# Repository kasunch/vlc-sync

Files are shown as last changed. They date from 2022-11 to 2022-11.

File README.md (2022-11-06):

# Harmony: A Time Synchronisation System for VLC Access Points

## About
This repository contains the implementation files for the paper titled **Harmony: A Time Synchronisation System for Visible Light Communication Access Points** published in ACM SenSys 2022. Access the paper here.

## Electronic Hardware

The electronic hardware consists of three modules.
* OWC Receiver module
* OWC Transmitter module
* ADC & DAC module

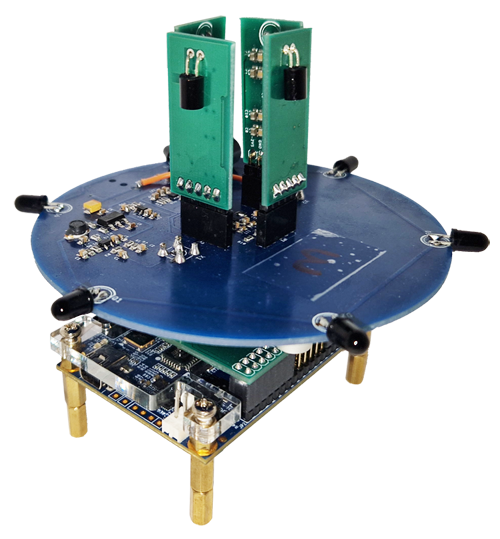
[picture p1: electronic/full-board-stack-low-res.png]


## Digital Hardware

The digital hardware implementation is done in Verilog.

**Note:**

The electronic and digital hardware implementations are fast-developed prototypes. Therefore, the implementations have several places which can be optimised.

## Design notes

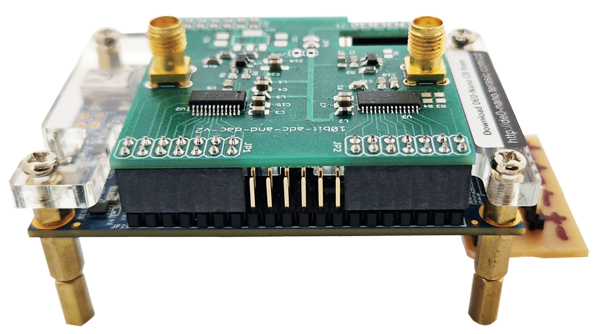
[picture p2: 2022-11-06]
electronic/10bit-adc-and-dac-low-res.png

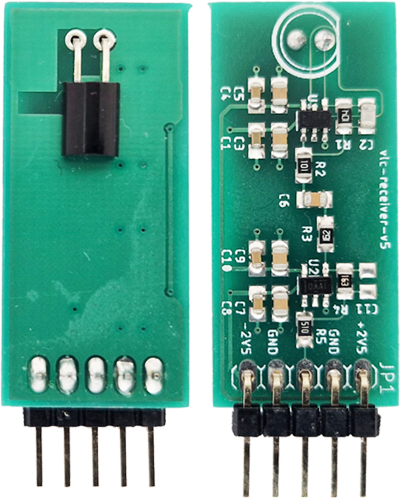
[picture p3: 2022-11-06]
electronic/owc-receiver-low-res.png

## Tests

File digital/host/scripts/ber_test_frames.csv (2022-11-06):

7c | 00 | 00 | 01 | 02 | 1e | 10 | 02 | 04 | 3c | 20 | 04 | 08 | 78 | 40 | 09 | 10 | 70 | 00 | 12 | 20 | 60 | 01 | 24 | 40 | 40 | 03 | 48 | 00 | 00 | 07 | 10 | 00 | 01 | 0f | 21 | 01 | 02 | 1e | 43 | 02 | 04 | 3c | 07 | 04 | 08 | 78 | 0e | 09 | 10 | 70 | 1d | 12 | 20 | 60 | 3b | 24 | 40 | 40 | 77
7c | 01 | 00 | 04 | 09 | 77 | 48 | 08 | 12 | 6e | 10 | 10 | 24 | 5c | 21 | 20 | 48 | 38 | 43 | 41 | 10 | 70 | 07 | 02 | 20 | 61 | 0e | 05 | 41 | 42 | 1d | 0b | 02 | 04 | 3b | 17 | 04 | 09 | 77 | 2f | 08 | 12 | 6e | 5e | 10 | 24 | 5c | 3c | 20 | 48 | 38 | 79 | 41 | 10 | 70 | 73 | 02 | 20 | 61 | 67
7c | 02 | 00 | 12 | 20 | 67 | 05 | 24 | 41 | 4f | 0b | 49 | 02 | 1e | 17 | 12 | 04 | 3d | 2f | 25 | 09 | 7a | 5e | 4a | 12 | 74 | 3c | 15 | 24 | 68 | 79 | 2a | 49 | 50 | 73 | 55 | 12 | 20 | 67 | 2b | 24 | 41 | 4f | 56 | 49 | 02 | 1e | 2d | 12 | 04 | 3d | 5b | 25 | 09 | 7a | 36 | 4a | 12 | 74 | 6d
7c | 03 | 00 | 00 | 52 | 6d | 15 | 00 | 24 | 5a | 2a | 01 | 48 | 35 | 55 | 03 | 10 | 6a | 2b | 07 | 20 | 55 | 56 | 0f | 40 | 2a | 2d | 1f | 00 | 54 | 5b | 3e | 00 | 29 | 36 | 7c | 00 | 52 | 6d | 78 | 00 | 24 | 5a | 70 | 01 | 48 | 35 | 60 | 03 | 10 | 6a | 40 | 07 | 20 | 55 | 01 | 0f | 40 | 2a | 03
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

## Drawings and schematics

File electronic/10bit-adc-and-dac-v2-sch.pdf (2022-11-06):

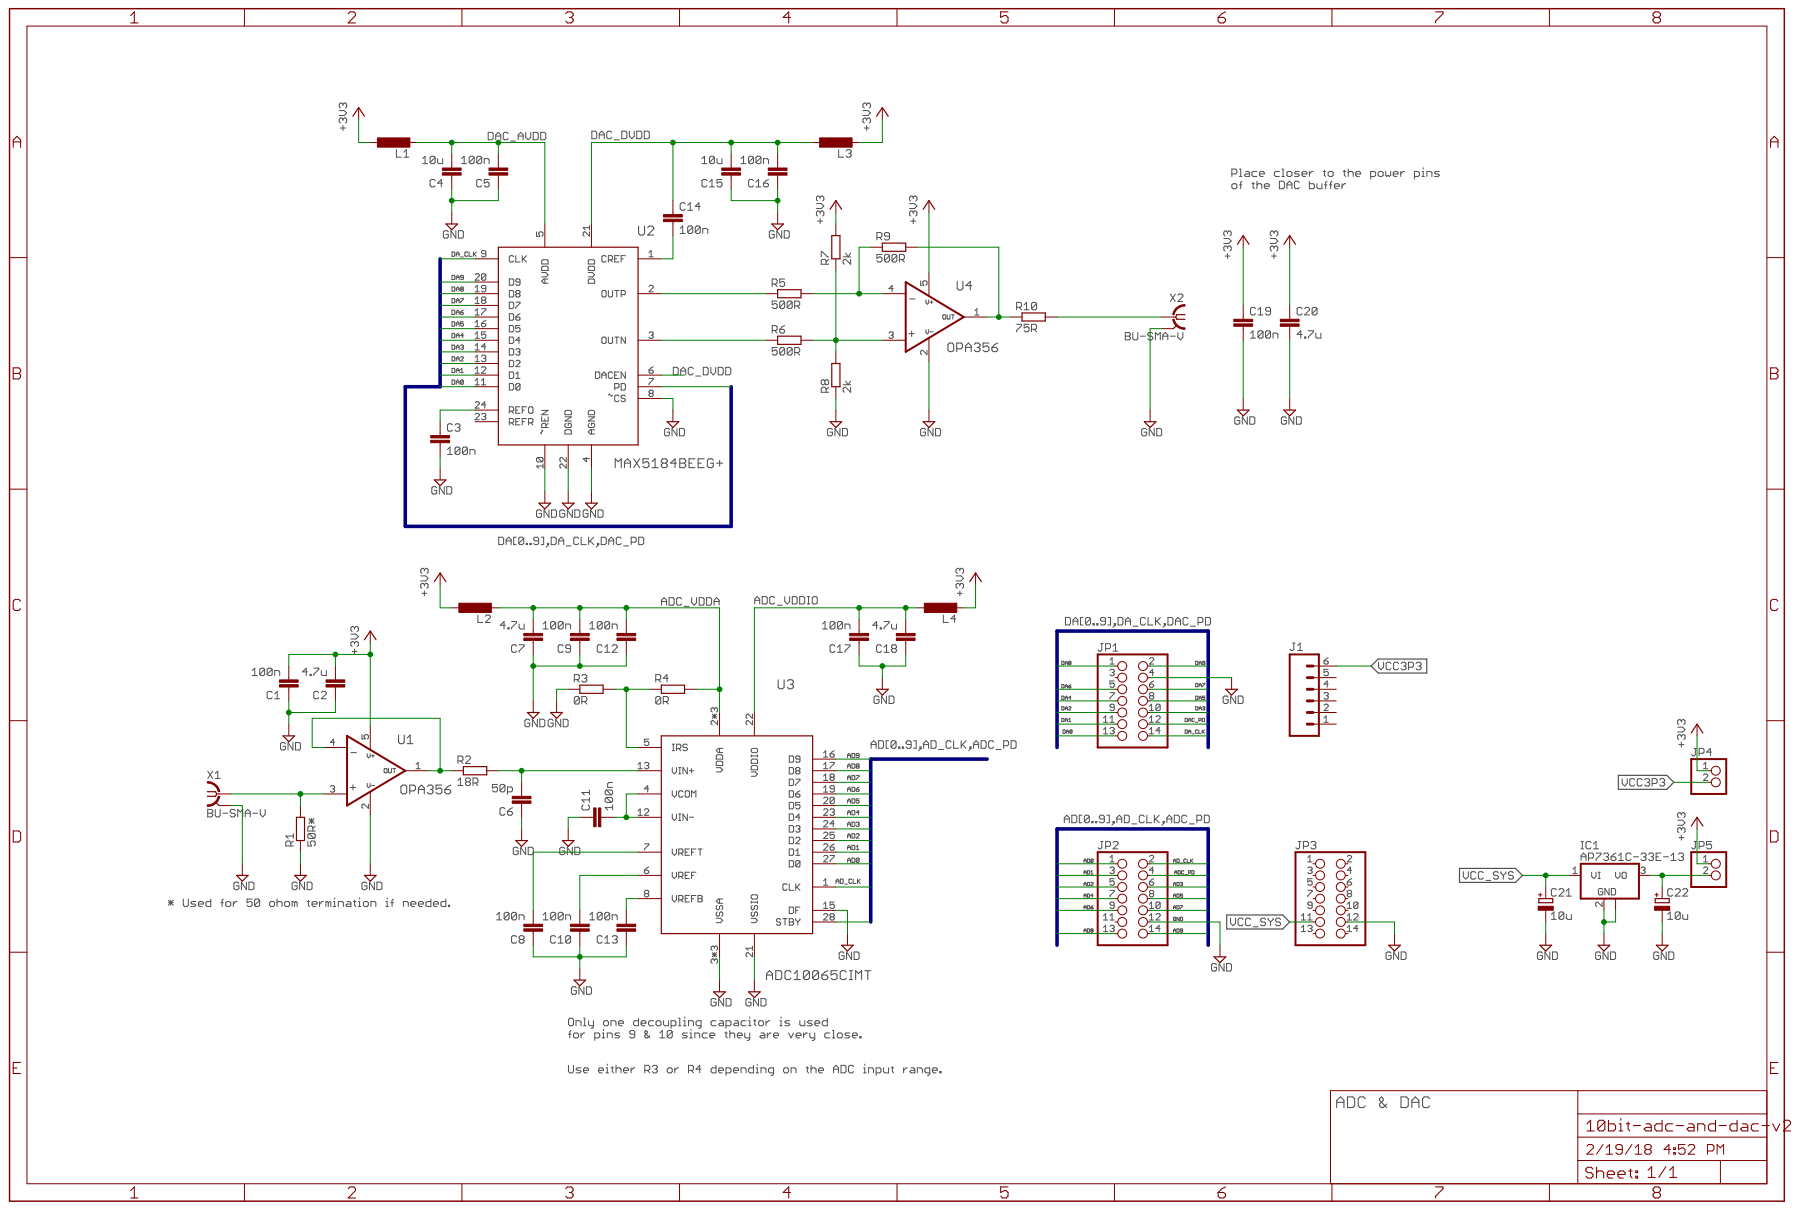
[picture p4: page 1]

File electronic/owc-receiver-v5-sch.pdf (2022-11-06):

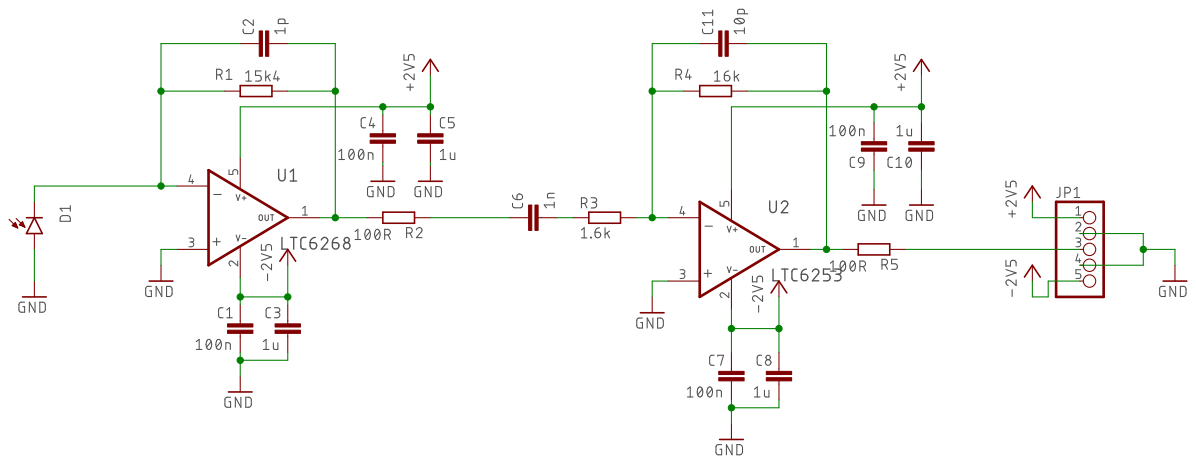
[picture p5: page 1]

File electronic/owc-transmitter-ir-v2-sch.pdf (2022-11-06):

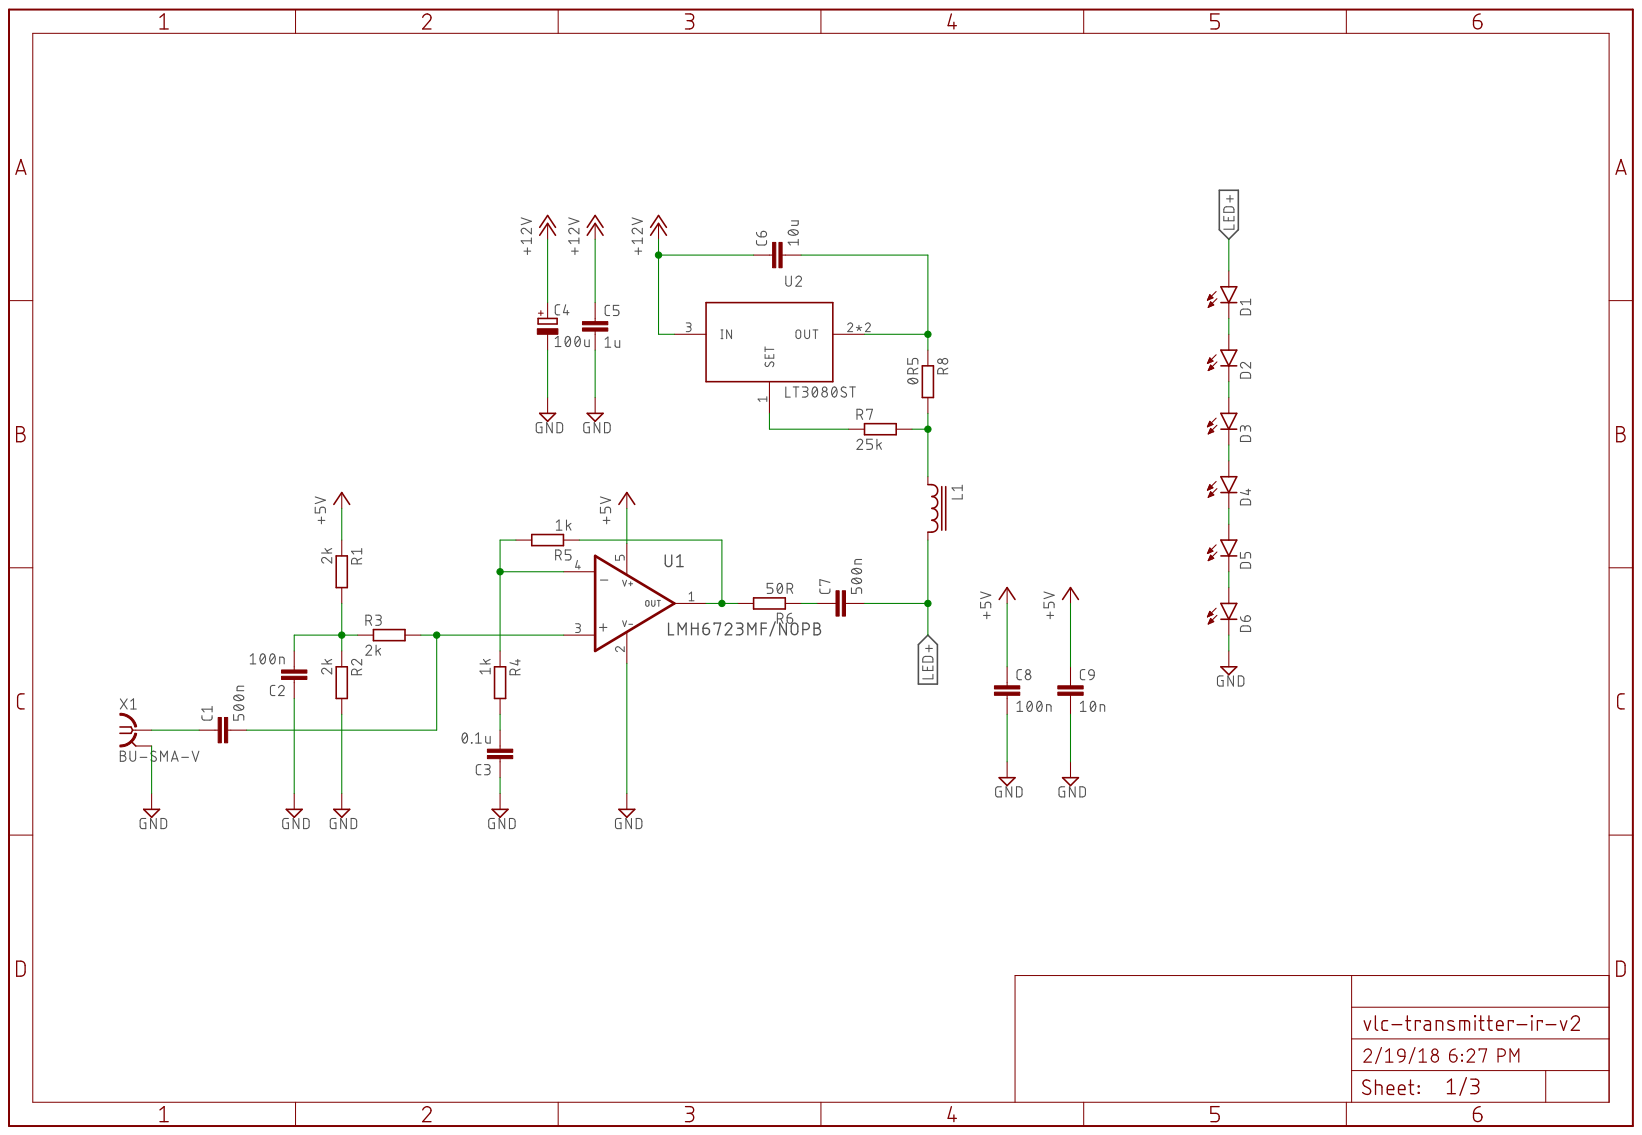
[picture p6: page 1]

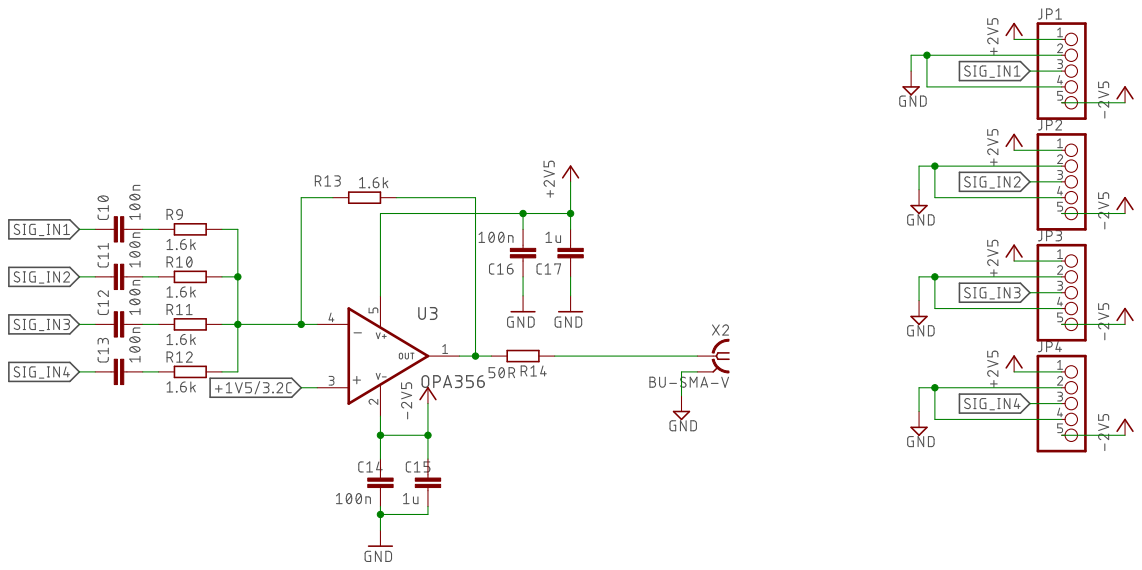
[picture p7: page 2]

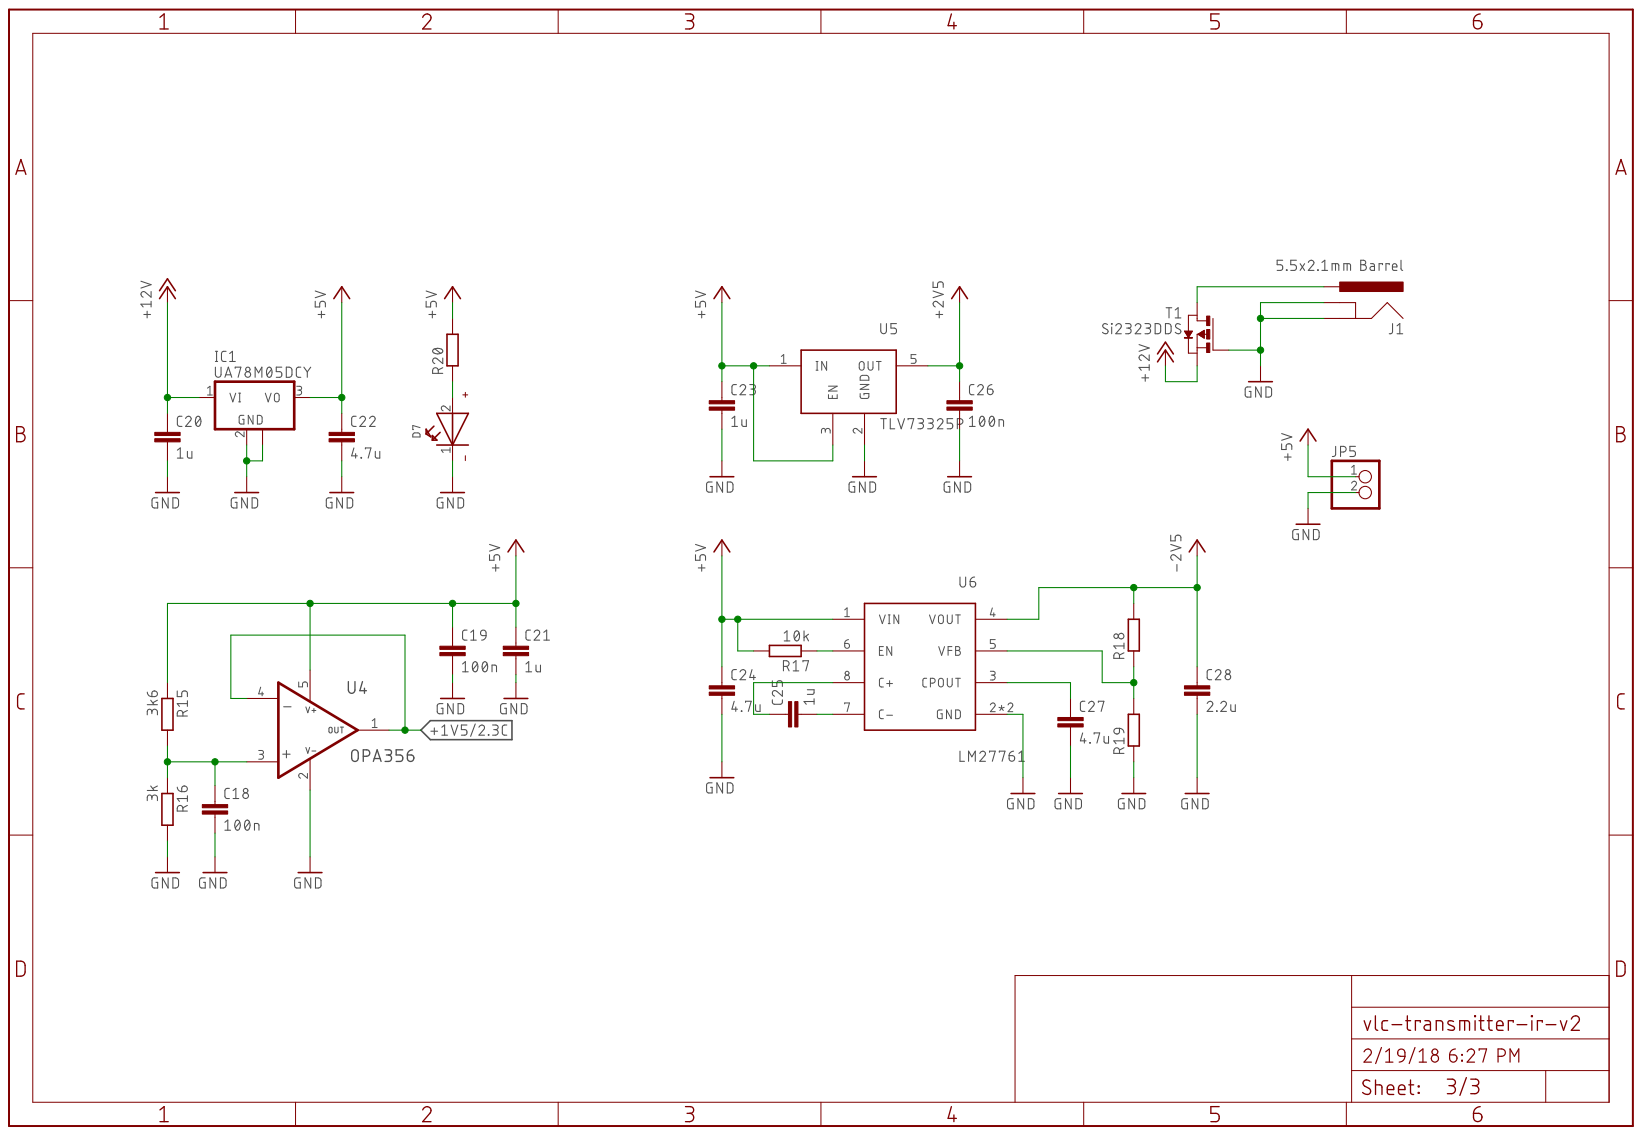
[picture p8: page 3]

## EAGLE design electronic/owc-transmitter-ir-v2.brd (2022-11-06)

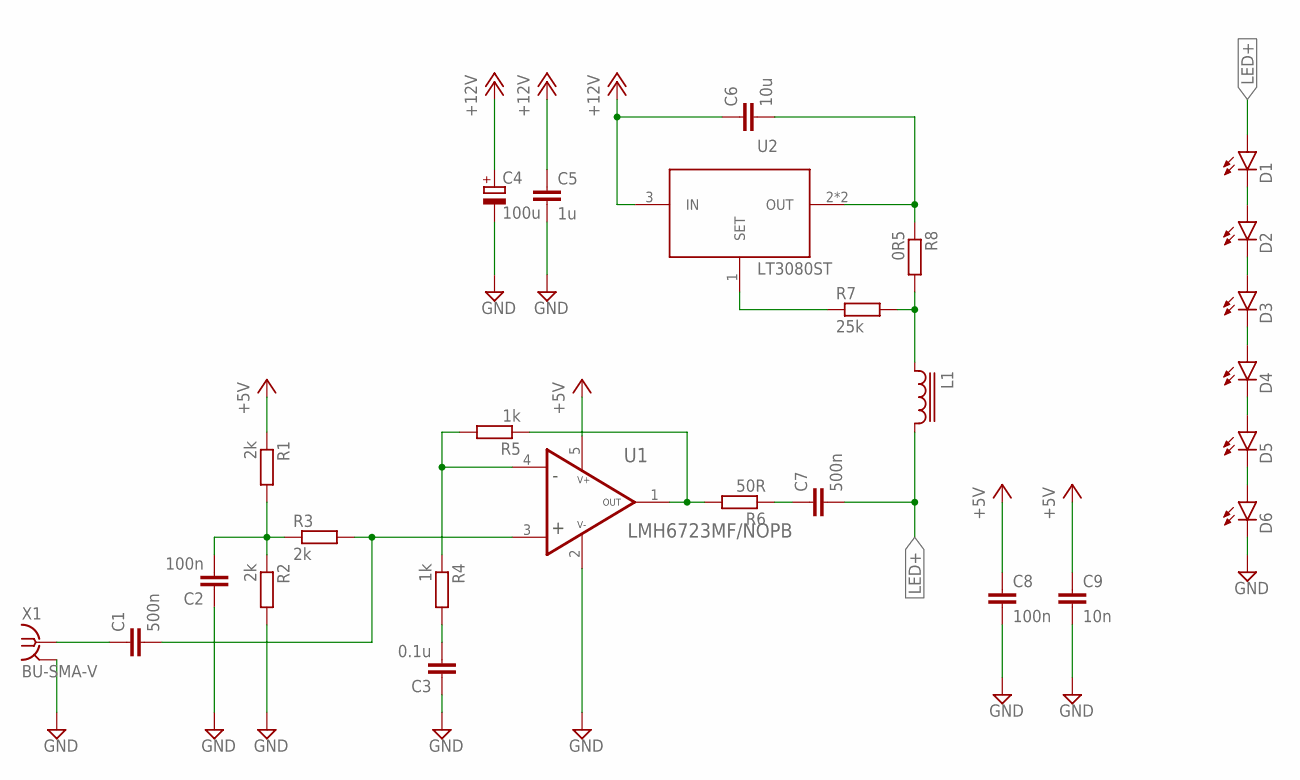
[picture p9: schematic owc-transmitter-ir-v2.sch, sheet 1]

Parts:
C1, C7: 500n; C0805
C2, C8: 100n; C0805
C3: 0.1u; C0805
C4: 100u; CT3528
C5: 1u; C0805
C6: 10u; C0805
C9: 10n; C0805
D1, D2, D3, D4, D5, D6: LED5MM
L1: SRR6603
R1, R2, R3: 2k; R0805
R4, R5: 1k; R0805
R6: 50R; R0805
R7: 25k; R0805
R8: 0R5; R0805
U1: LMH6723MF/NOPB; SOT23-5L
U2: LT3080ST; SOT223
X1: BU-SMA-V

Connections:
+5V: C8.1, C9.1, R1.1, U1.5 (V+); also elsewhere on the board
+12V: C4.+, C5.1, C6.1, U2.3 (IN); also elsewhere on the board
GND: C2.1, C3.1, C4.-, C5.2, C8.2, C9.2, D6.K (C), R2.2, U1.2 (V-), X1.2, X1.3 (2), X1.4 (2), X1.5 (2); also elsewhere on the board
LED+: C7.2, D1.A, L1.P$2 (2)
unnamed: D1.K (C), D2.A
unnamed: D2.K (C), D3.A
unnamed: D3.K (C), D4.A
unnamed: D4.K (C), D5.A
unnamed: D5.K (C), D6.A
unnamed: R5.1, R6.2, U1.1 (OUT)
unnamed: C7.1, R6.1
unnamed: R4.1, R5.2, U1.4 (IN-)
unnamed: C6.2, R8.1, U2.2 (OUT), U2.4 (OUT)
unnamed: C3.2, R4.2
unnamed: L1.P$1 (1), R7.2, R8.2
unnamed: C2.2, R1.2, R2.1, R3.1
unnamed: C1.1, X1.1
unnamed: R7.1, U2.1 (SET)
unnamed: C1.2, R3.2, U1.3 (IN+)

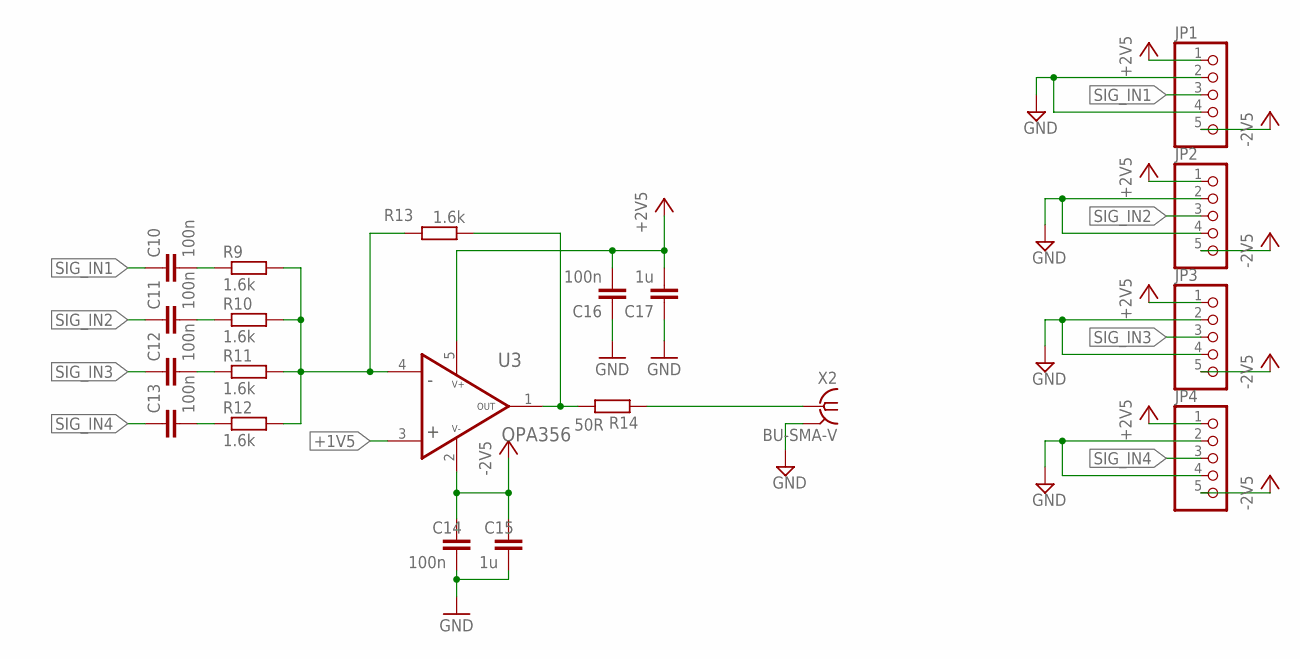
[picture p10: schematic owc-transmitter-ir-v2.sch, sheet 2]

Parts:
C10, C11, C12, C13, C14, C16: 100n; C0805
C15, C17: 1u; C0805
JP1, JP2, JP3, JP4: PINHD-1X5; 1X05
R9, R10, R11, R12, R13: 1.6k; R0805
R14: 50R; R0805
U3: OPA356; SOT23-5L
X2: BU-SMA-V

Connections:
+1V5: U3.3 (IN+); also elsewhere on the board
+2V5: C16.2, C17.2, JP1.1, JP2.1, JP3.1, JP4.1, U3.5 (V+); also elsewhere on the board
-2V5: C14.1, C15.1, JP1.5, JP2.5, JP3.5, JP4.5, U3.2 (V-); also elsewhere on the board
GND: C14.2, C15.2, C16.1, C17.1, JP1.2, JP1.4, JP2.2, JP2.4, JP3.2, JP3.4, JP4.2, JP4.4, X2.2, X2.3 (2), X2.4 (2), X2.5 (2); also elsewhere on the board
unnamed: R13.1, R14.2, U3.1 (OUT)
unnamed: C12.2, R11.1
unnamed: R9.2, R10.2, R11.2, R12.2, R13.2, U3.4 (IN-)
unnamed: R14.1, X2.1
unnamed: C11.2, R10.1
unnamed: C13.2, R12.1
unnamed: C10.2, R9.1
SIG_IN1: C10.1, JP1.3
SIG_IN2: C11.1, JP2.3
SIG_IN3: C12.1, JP3.3
SIG_IN4: C13.1, JP4.3

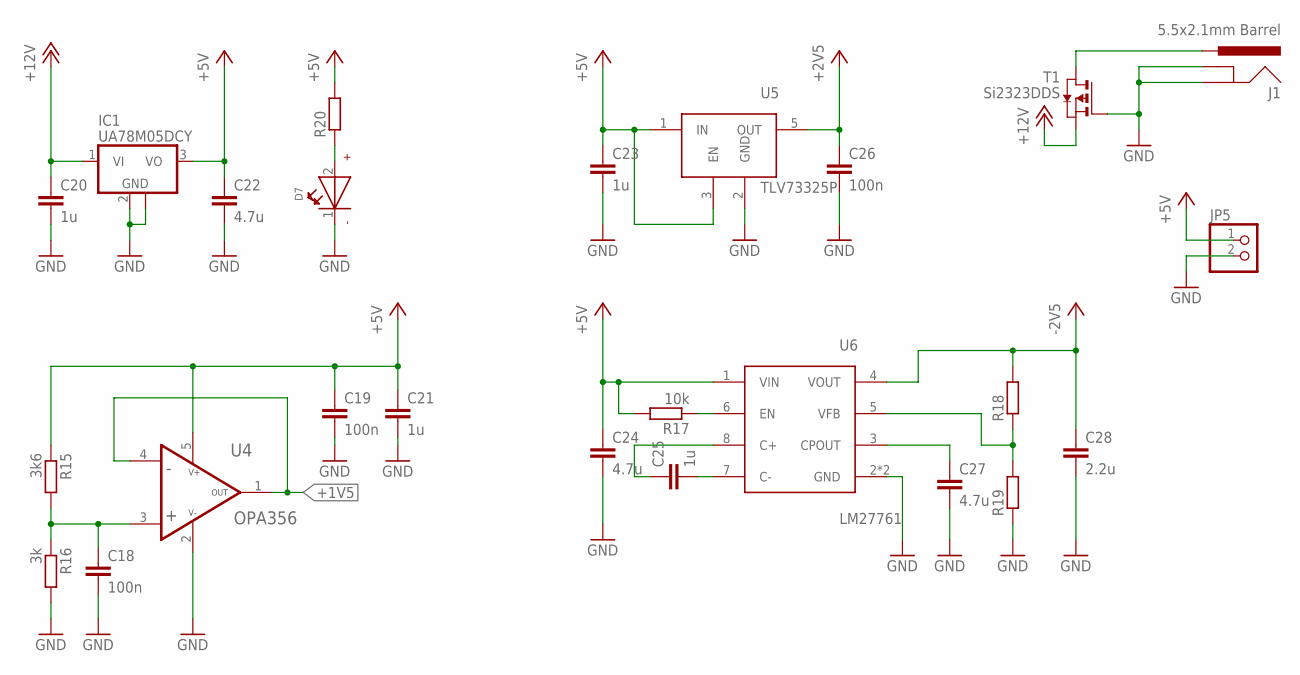
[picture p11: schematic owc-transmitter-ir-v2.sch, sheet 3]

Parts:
C18, C19, C26: 100n; C0805
C20, C21, C23, C25: 1u; C0805
C22, C24, C27: 4.7u; C0805
C28: 2.2u; C0805
D7: WL-SMCW-150080GS75000-G; WL-SMCW_0805
IC1: UA78M05DCY; SOT223
J1: 5.5x2.1mm Barrel; POWER_JACK_SMD
JP5: PINHD-1X2; 1X02
R15: 3k6; R0805
R16: 3k; R0805
R17: 10k; R0805
R18, R19, R20: R-EU_R0805; R0805
T1: Si2323DDS; SOT-23
U4: OPA356; SOT23-5L
U5: TLV73325P; SOT23-5L
U6: LM27761DSG; WSON-8-PAD; MPN LM27761DSGT

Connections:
+1V5: U4.1 (OUT), U4.4 (IN-); also elsewhere on the board
+2V5: C26.1, U5.5 (OUT); also elsewhere on the board
+5V: C19.1, C21.1, C22.1, C23.1, C24.1, IC1.3 (VO), JP5.1, R15.1, R17.2, R20.2, U4.5 (V+), U5.1 (IN), U5.3 (EN), U6.1 (VIN); also elsewhere on the board
+12V: C20.1, IC1.1 (VI), T1.2 (S); also elsewhere on the board
-2V5: C28.1, R18.2, U6.4 (VOUT); also elsewhere on the board
GND: C18.2, C19.2, C20.2, C21.2, C22.2, C23.2, C24.2, C26.2, C27.2, C28.2, D7.1 (-), IC1.2 (GND), IC1.4 (GND), J1.GND (GNDBREAK), J1.P$4 (GND), JP5.2, R16.2, R19.1, T1.3 (G), U4.2 (V-), U5.2 (GND), U6.2 (GND), U6.PAD (GND); also elsewhere on the board
unnamed: C27.1, U6.3 (CPOUT)
unnamed: C25.1, U6.8 (C+)
unnamed: C25.2, U6.7 (C-)
unnamed: D7.2 (+), R20.1
unnamed: R17.1, U6.6 (EN)
unnamed: R18.1, R19.2, U6.5 (VFB)
unnamed: C18.1, R15.2, R16.1, U4.3 (IN+)
unnamed: J1.VIN0 (PWR), T1.1 (D)

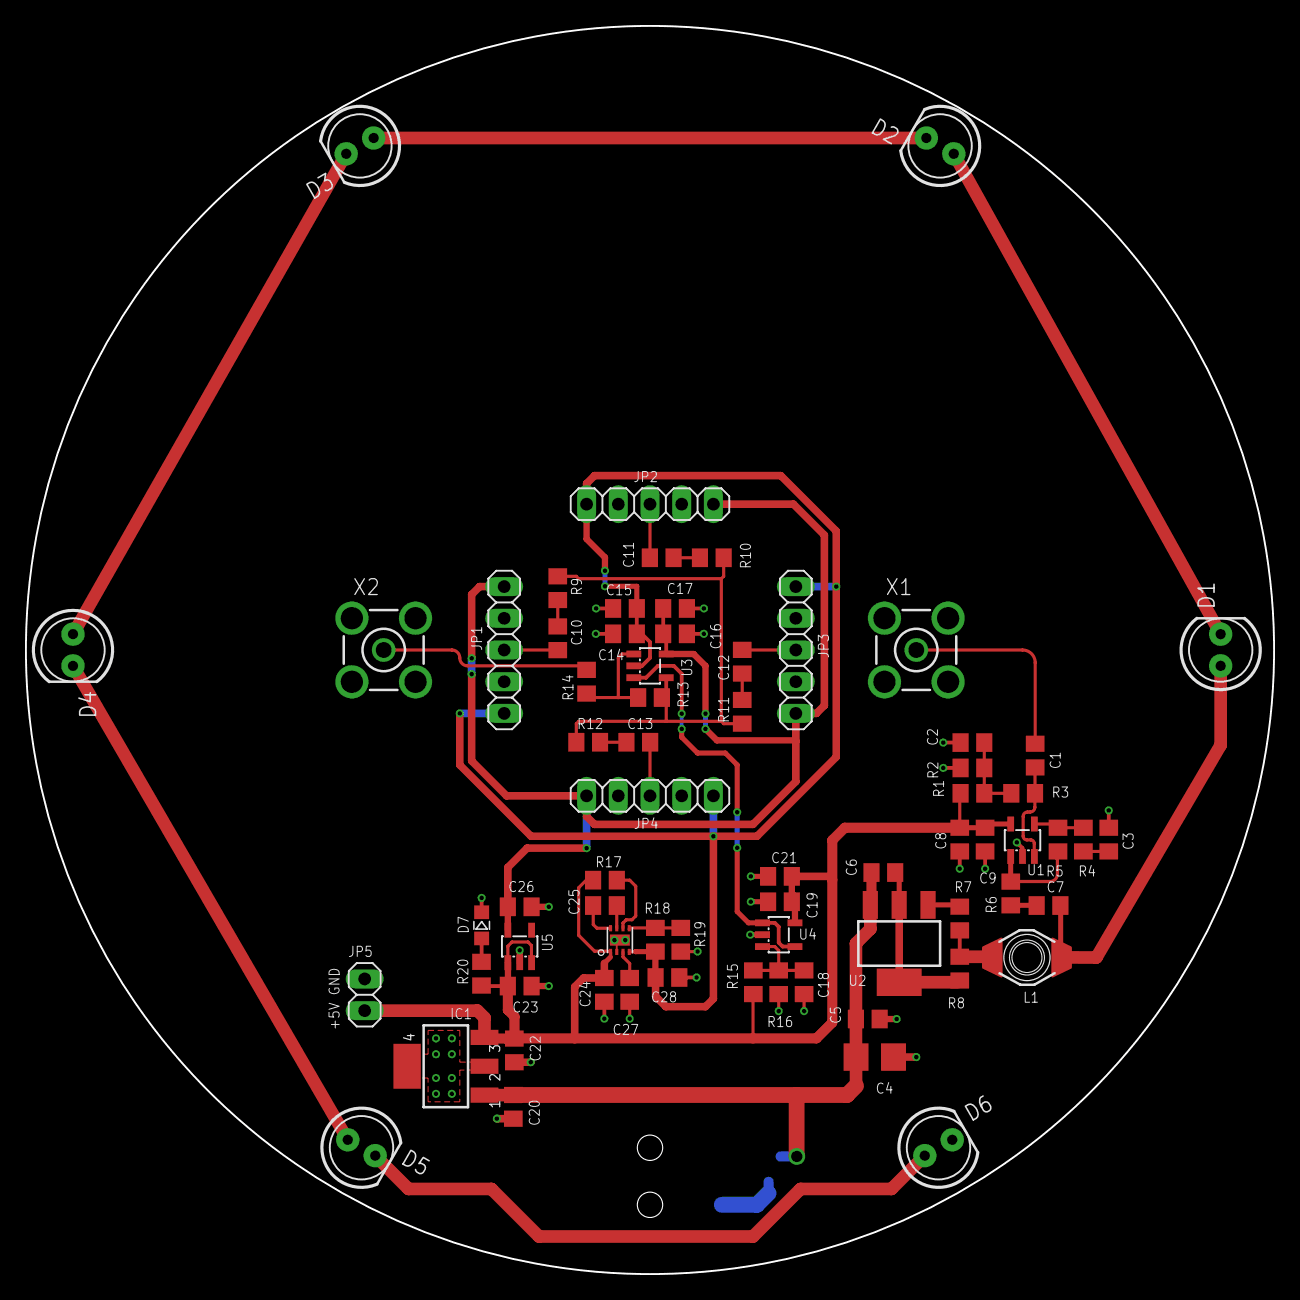
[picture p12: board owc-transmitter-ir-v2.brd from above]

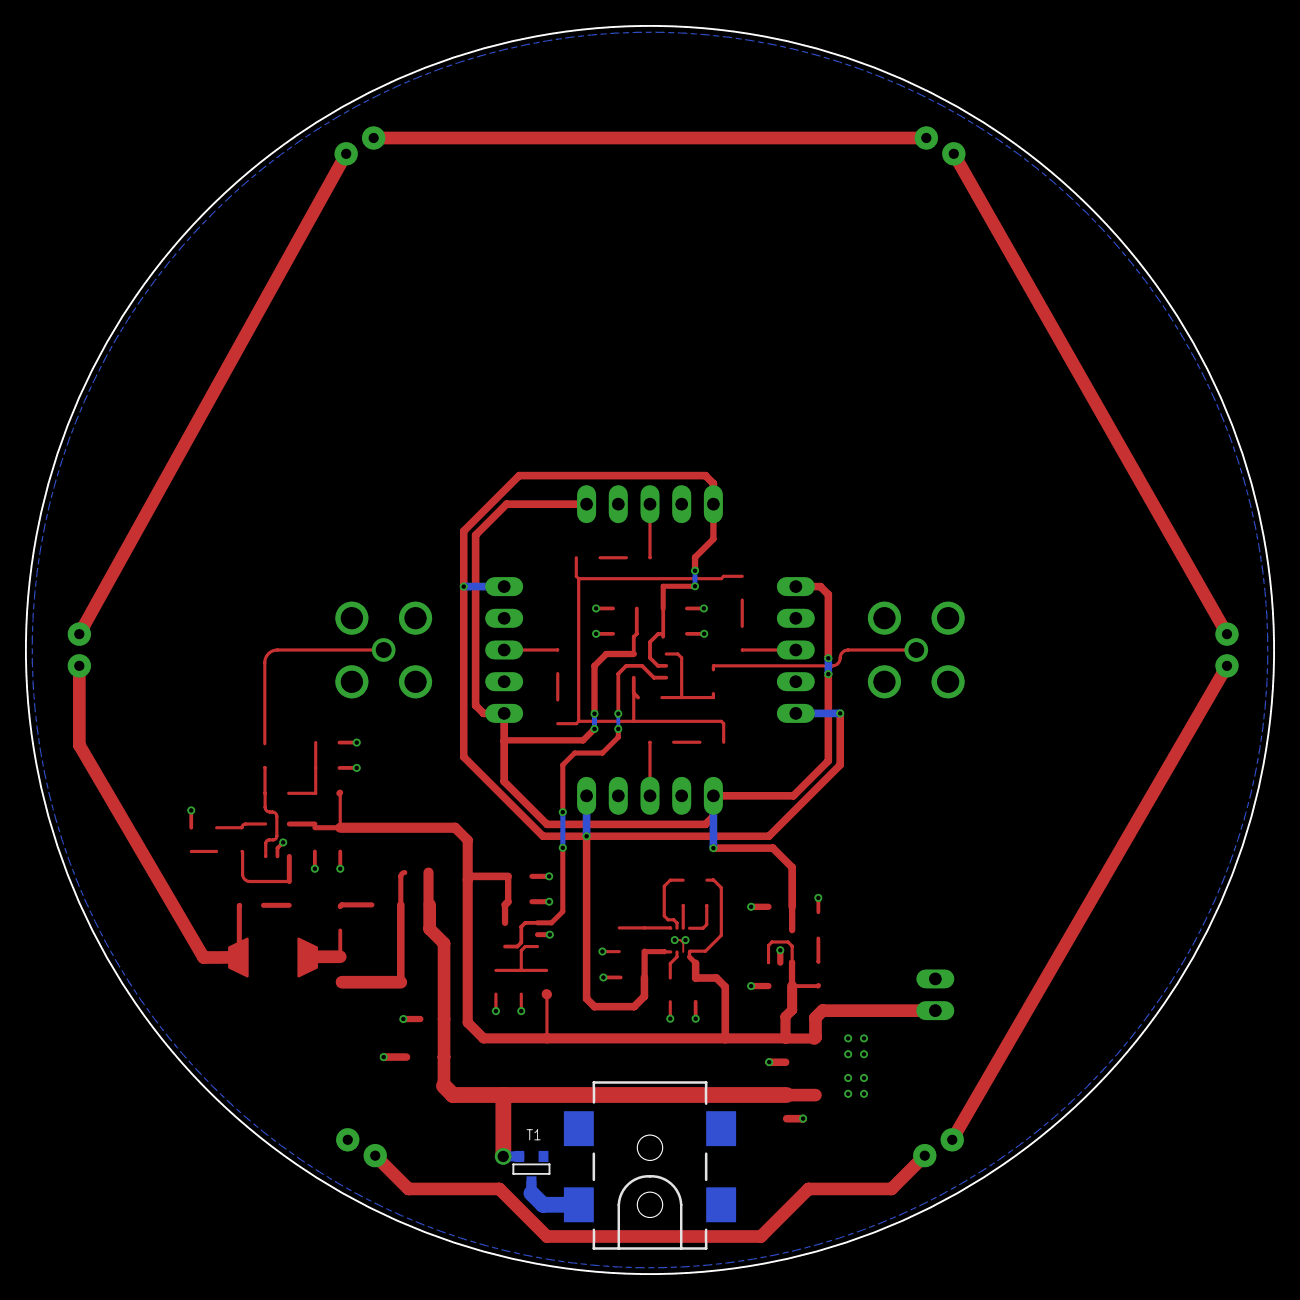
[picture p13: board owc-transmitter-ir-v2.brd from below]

Board: 2 copper layers, 100.0 x 100.0 mm, 72 parts (2 on the bottom side), 41 nets.

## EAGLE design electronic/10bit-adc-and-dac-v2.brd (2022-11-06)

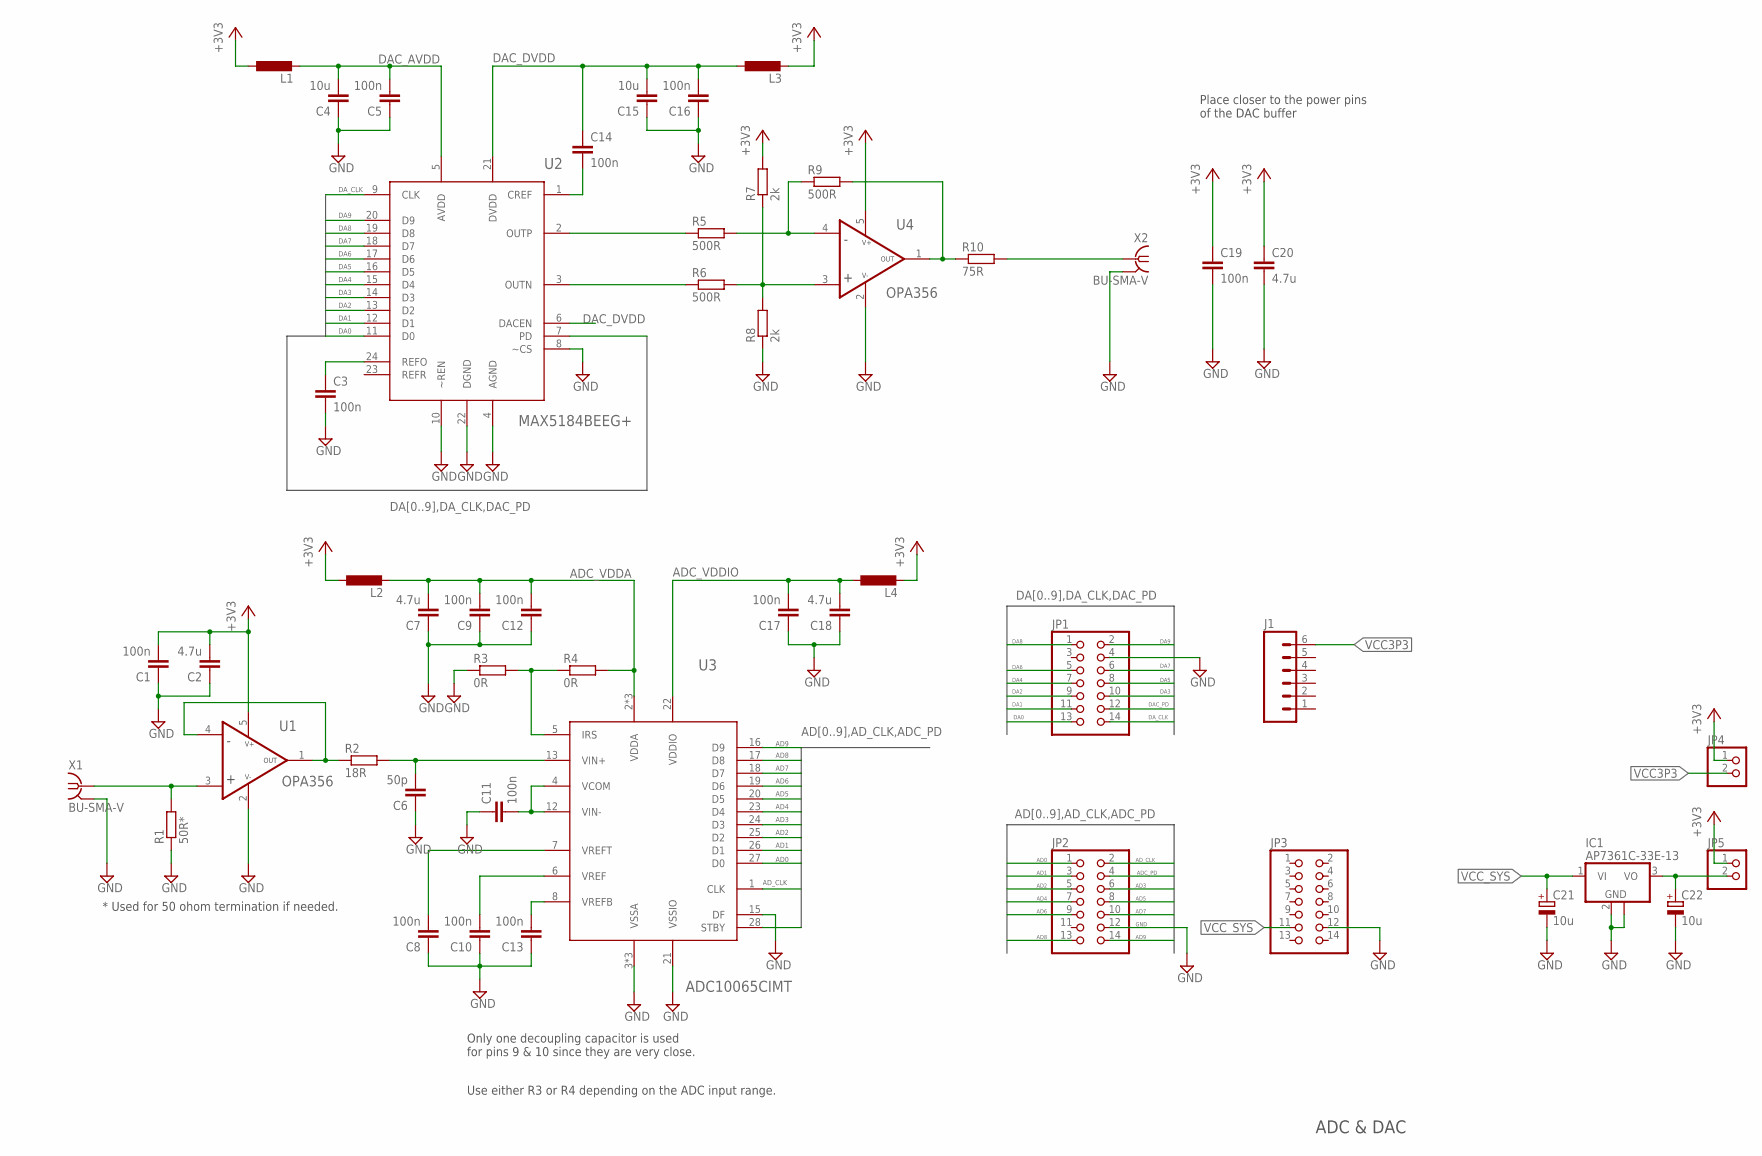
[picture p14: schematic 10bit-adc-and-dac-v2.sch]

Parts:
C1, C3, C5, C8, C9, C10, C11, C12, C13, C14, C16, C17, C19: 100n; C0805
C2, C7, C18, C20: 4.7u; C0805
C4, C15: 10u; C0805
C6: 50p; C0805
C21, C22: 10u; CT3528
IC1: AP7361C-33E-13; SOT223; MPN AP7361C-33E-13
J1: M06SILK_FEMALE_PTH; 1X06
JP1, JP2, JP3: PINHD-2X7; 2X07
JP4, JP5: PINHD-1X2; 1X02
L1, L2, L3, L4: L-EUL2012C; L2012C; MPN CIM21J252NE
R1: 50R*; R0805
R2: 18R; R0805
R3, R4: 0R; R0805
R5, R6, R9: 500R; R0805
R7, R8: 2k; R0805
R10: 75R; R0805
U1, U4: OPA356; SOT23-5L; MPN OPA356AIDBVR
U2: MAX5184BEEG+; SOP63P600X175-24N; MPN MAX5184BEEG+
U3: ADC10065CIMT; TSSOP28; MPN ADC10065CIMTX/NOPB
X1, X2: BU-SMA-V; MPN 5-1814832-1

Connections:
+3V3: C1.2, C2.2, C19.1, C20.1, JP4.1, JP5.1, L1.1, L2.1, L3.2, L4.2, R7.2, U1.5 (V+), U4.5 (V+)
AD0: JP2.1, U3.27 (D0)
AD1: JP2.3, U3.26 (D1)
AD2: JP2.5, U3.25 (D2)
AD3: JP2.6, U3.24 (D3)
AD4: JP2.7, U3.23 (D4)
AD5: JP2.8, U3.20 (D5)
AD6: JP2.9, U3.19 (D6)
AD7: JP2.10, U3.18 (D7)
AD8: JP2.13, U3.17 (D8)
AD9: JP2.14, U3.16 (D9)
ADC_PD: JP2.4, U3.28 (STBY)
ADC_VDDA: C7.2, C9.2, C12.2, L2.2, R4.2, U3.2 (VDDA), U3.9 (VDDA), U3.10 (VDDA)
ADC_VDDIO: C17.2, C18.2, L4.1, U3.22 (VDDIO)
AD_CLK: JP2.2, U3.1 (CLK)
DA0: JP1.13, U2.11 (D0)
DA1: JP1.11, U2.12 (D1)
DA2: JP1.9, U2.13 (D2)
DA3: JP1.10, U2.14 (D3)
DA4: JP1.7, U2.15 (D4)
DA5: JP1.8, U2.16 (D5)
DA6: JP1.5, U2.17 (D6)
DA7: JP1.6, U2.18 (D7)
DA8: JP1.1, U2.19 (D8)
DA9: JP1.2, U2.20 (D9)
DAC_AVDD: C4.2, C5.2, L1.2, U2.5 (AVDD)
DAC_DVDD: C14.1, C15.2, C16.2, L3.1, U2.6 (DACEN), U2.21 (DVDD)
DAC_PD: JP1.12, U2.7 (PD)
DA_CLK: JP1.14, U2.9 (CLK)
GND: C1.1, C2.1, C3.2, C4.1, C5.1, C6.1, C7.1, C8.1, C9.1, C10.1, C11.1, C12.1, C13.1, C15.1, C16.1, C17.1, C18.1, C19.2, C20.2, C21.-, C22.-, IC1.2 (GND), IC1.4 (GND), JP1.4, JP2.12, JP3.12, R1.1, R3.1, R8.1, U1.2 (V-), U2.4 (AGND), U2.8 (~CS), U2.10 (~REN), U2.22 (DGND), U3.3 (VSSA), U3.11 (VSSA), U3.14 (VSSA), U3.15 (DF), U3.21 (VSSIO), U4.2 (V-), X1.2, X1.3 (2), X1.4 (2), X1.5 (2), X2.2, X2.3 (2), X2.4 (2), X2.5 (2)
unnamed: R2.1, U1.1 (OUT), U1.4 (IN-)
unnamed: R10.2, X2.1
unnamed: R1.2, U1.3 (IN+), X1.1
unnamed: C22.+, IC1.3 (VO), JP5.2
unnamed: R3.2, R4.1, U3.5 (IRS)
unnamed: C13.2, U3.8 (VREFB)
unnamed: C6.2, R2.2, U3.13 (VIN+)
unnamed: C10.2, U3.6 (VREF)
unnamed: C3.1, U2.24 (REFO)
unnamed: C14.2, U2.1 (CREF)
unnamed: C8.2, U3.7 (VREFT)
unnamed: C11.2, U3.4 (VCOM), U3.12 (VIN-)
unnamed: R9.2, R10.1, U4.1 (OUT)
unnamed: R6.2, R7.1, R8.2, U4.3 (IN+)
unnamed: R5.2, R9.1, U4.4 (IN-)
unnamed: R5.1, U2.2 (OUTP)
unnamed: R6.1, U2.3 (OUTN)
VCC3P3: J1.6, JP4.2
VCC_SYS: C21.+, IC1.1 (VI), JP3.11

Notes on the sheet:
Place closer to the power pins of the DAC buffer
Only one decoupling capacitor is used for pins 9 & 10 since they are very close.
ADC & DAC
* Used for 50 ohom termination if needed.
Use either R3 or R4 depending on the ADC input range.

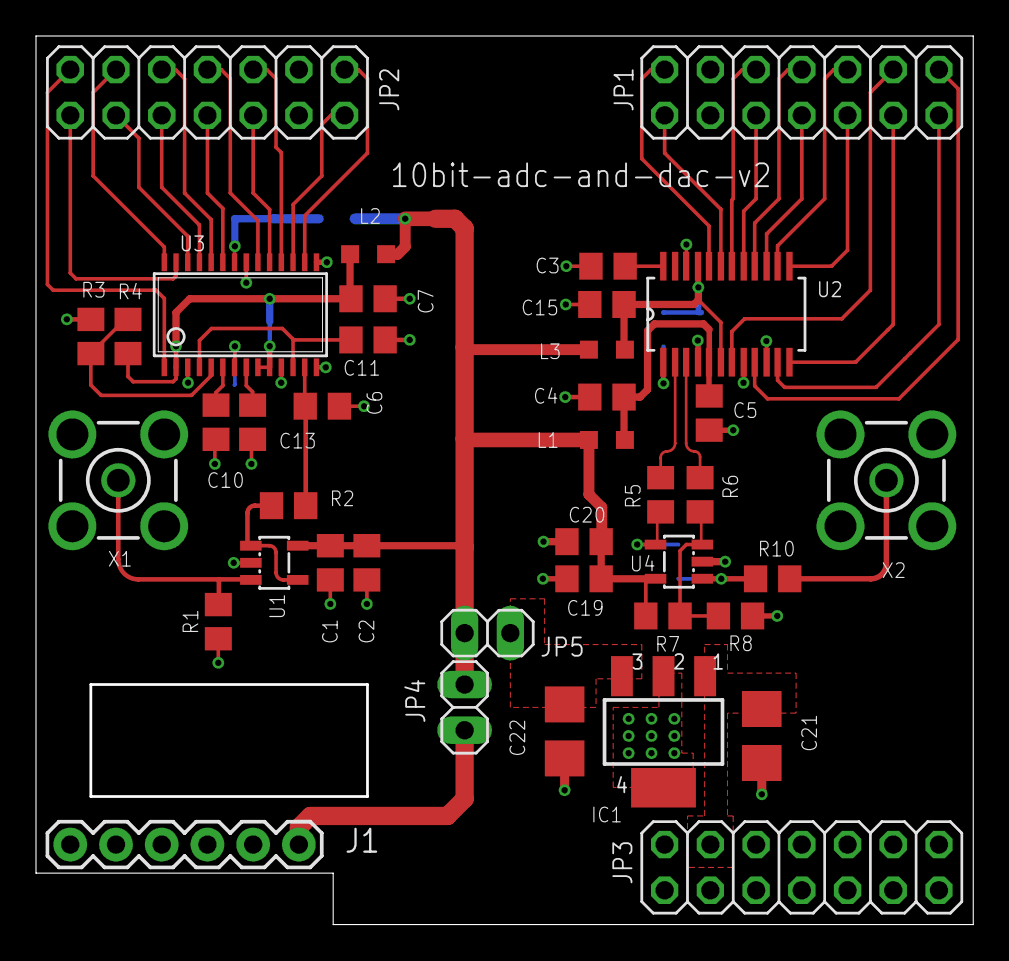
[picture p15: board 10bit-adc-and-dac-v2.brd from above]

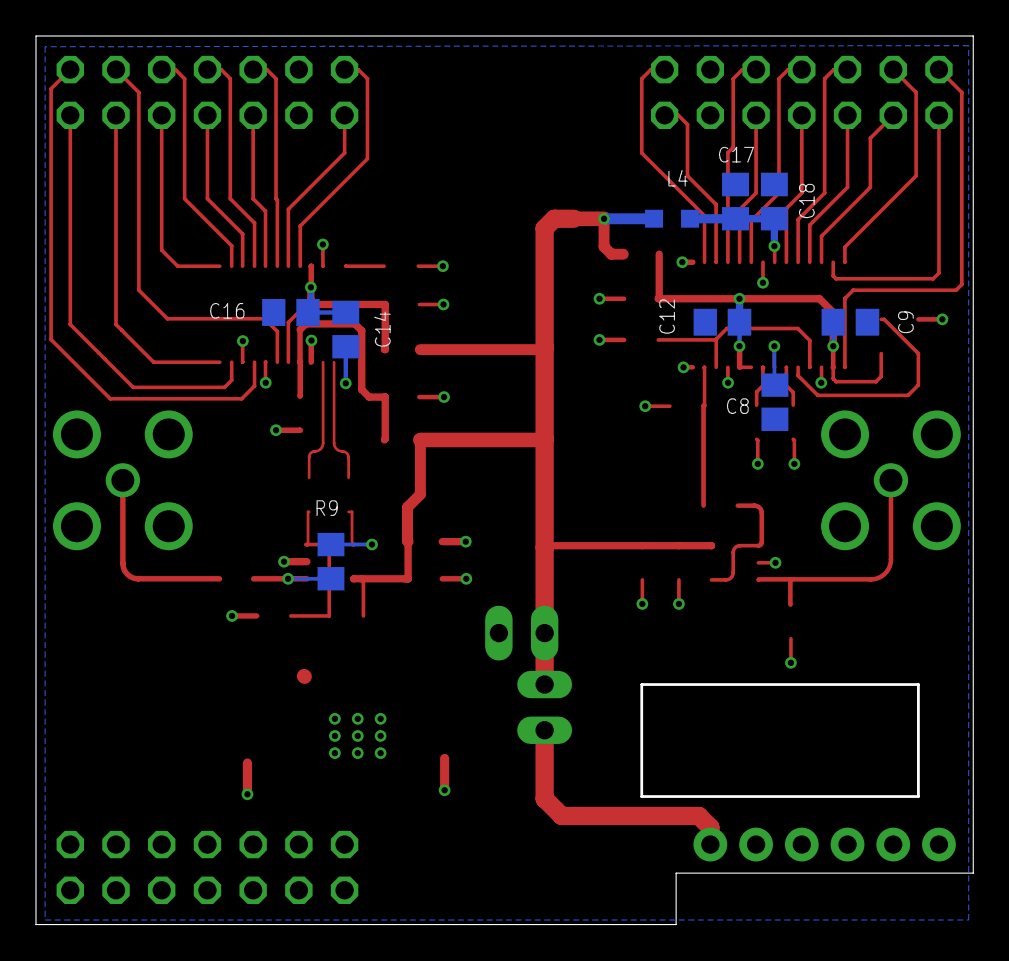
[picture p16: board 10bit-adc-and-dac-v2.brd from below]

Board: 2 copper layers, 52.1 x 49.4 mm, 49 parts (9 on the bottom side), 49 nets.

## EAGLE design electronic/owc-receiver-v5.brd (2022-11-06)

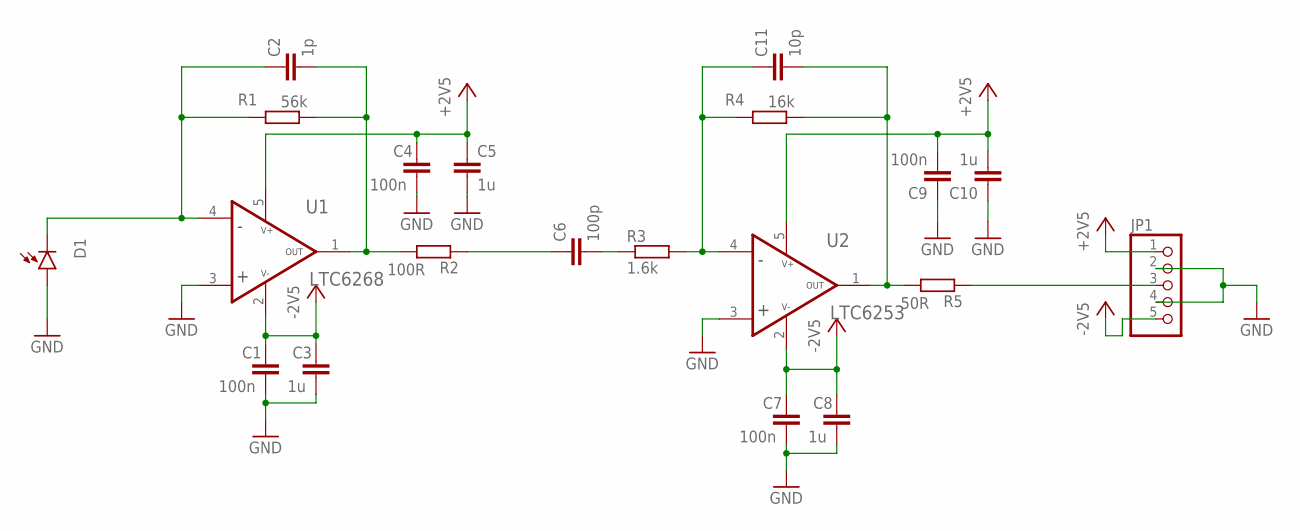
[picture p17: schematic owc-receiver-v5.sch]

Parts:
C1, C4, C7, C9: 100n; C0805
C2: 1p; C0805
C3, C5, C8, C10: 1u; C0805
C6: 100p; C0805
C11: 10p; C0805
D1: PHOTODIODE5MM; LED5MM
JP1: PINHD-1X5; 1X05
R1: 56k; R0805
R2: 100R; R0805
R3: 1.6k; R0805
R4: 16k; R0805
R5: 50R; R0805
U1: LTC6268; SOT23-5L
U2: LTC6253; SOT23-5L

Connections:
+2V5: C4.1, C5.1, C9.2, C10.2, JP1.1, U1.5 (V+), U2.5 (V+)
-2V5: C1.1, C3.1, C7.1, C8.1, JP1.5, U1.2 (V-), U2.2 (V-)
GND: C1.2, C3.2, C4.2, C5.2, C7.2, C8.2, C9.1, C10.1, D1.A, JP1.2, JP1.4, U1.3 (IN+), U2.3 (IN+)
unnamed: C11.2, R4.1, R5.2, U2.1 (OUT)
unnamed: C2.2, R1.1, R2.2, U1.1 (OUT)
unnamed: C6.1, R2.1
unnamed: C6.2, R3.1
unnamed: C2.1, D1.K (C), R1.2, U1.4 (IN-)
unnamed: C11.1, R3.2, R4.2, U2.4 (IN-)
unnamed: JP1.3, R5.1

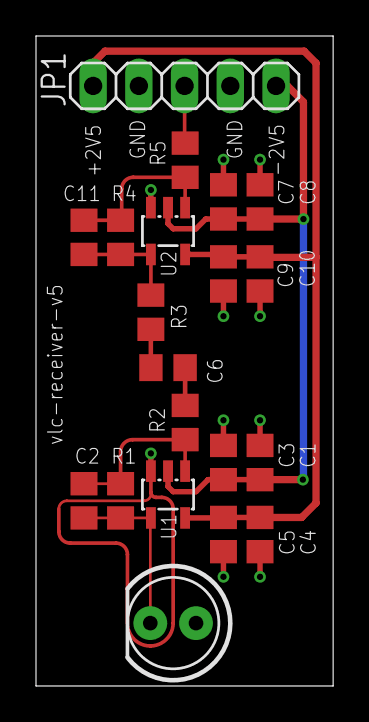
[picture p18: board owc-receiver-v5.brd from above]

Board: 2 copper layers, 16.5 x 36.1 mm, 20 parts (0 on the bottom side), 10 nets.

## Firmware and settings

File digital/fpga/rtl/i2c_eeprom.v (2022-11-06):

`define I2C_EEPROM_STATE_IDLE          3'd0
`define I2C_EEPROM_STATE_SET_ADDR      3'd1
`define I2C_EEPROM_STATE_WRITE         3'd2
`define I2C_EEPROM_STATE_INIT_READ     3'd3
`define I2C_EEPROM_STATE_READ          3'd4
`define I2C_EEPROM_STATE_WAIT_CYCLE    3'd5
`define I2C_EEPROM_STATE_WAIT_END      3'd6

module i2c_eeprom(clk, reset,
            // module interface
            i_start,    // Start operation
            i_mode,     // 0: read, 1:write
            i_dev_addr, // I2C device address
            i_page_addr, // I2C device address
            i_page_b0, i_page_b1, i_page_b2, i_page_b3, i_page_b4, i_page_b5, i_page_b6, i_page_b7,
            o_page_b0, o_page_b1, o_page_b2, o_page_b3, o_page_b4, o_page_b5, o_page_b6, o_page_b7,
            o_done,
            o_busy,
            // I2C interface
            i_sda,
            o_sda,
            t_sda,
            i_scl,
            o_scl,
            t_scl,
            i_prescale);

    input       clk;
    input       reset;
    // module interface
    input            i_start;
    input            i_mode;
    input [6:0]      i_dev_addr; 
    input [7:0]      i_page_addr;           
    input [7:0]      i_page_b0, i_page_b1, i_page_b2, i_page_b3, i_page_b4, i_page_b5, i_page_b6, i_page_b7;
    output[7:0]      o_page_b0, o_page_b1, o_page_b2, o_page_b3, o_page_b4, o_page_b5, o_page_b6, o_page_b7;
    output reg       o_done = 0;
    output           o_busy;
    // I2C interface
    input            i_sda;
    output           o_sda;
    output           t_sda;
    input            i_scl;
    output           o_scl;
    output           t_scl;
    // Clock prescale
    input [15:0]     i_prescale;

    // Registers and wires for i2c master module
    reg         r_i2c_cmd_write = 0;   // Write single byte
    reg         r_i2c_cmd_write_m = 0; // Write multiple bytes
    reg         r_i2c_cmd_read_m = 0;  // Read multiple bytes
    reg         r_i2c_cmd_valid = 0;   // Indicate when the command is valid
    reg         r_i2c_set_stop_at_end = 0;
    reg [7:0]   r_i2c_data_in;
    reg         r_i2c_data_in_valid = 0;
    reg         r_i2c_data_in_last = 0;
    reg         r_i2c_data_out_ready = 0;

    wire        w_i2c_cmd_ready; 
    wire        w_i2c_data_in_ready; 
    wire [7:0]  w_i2c_data_out;
    wire        w_i2c_data_out_valid;
    wire        w_i2c_data_out_last;
    wire        w_i2c_bus_control;
    wire        w_i2c_missed_ack;

    // Other internal registers and wires
    reg         r_mode = 0;
    reg [6:0]   r_i2c_dev_addr = 0;
    reg [7:0]   r_i2c_mem_addr = 0;
    reg [7:0]   r_page_bytes [7:0];
    reg [2:0]   r_state = `I2C_EEPROM_STATE_IDLE;
    reg [2:0]   r_nxt_state = `I2C_EEPROM_STATE_IDLE;
    reg [7:0]   r_byte_idx = 0;

    i2c_master i2c_inst (.clk(clk), .rst(reset),
                        .cmd_address(r_i2c_dev_addr),
                        //.cmd_start(cmd_start),
                        .cmd_read(r_i2c_cmd_read_m),
                        .cmd_write(r_i2c_cmd_write),
                        .cmd_write_multiple(r_i2c_cmd_write_m),
                        .cmd_stop(r_i2c_set_stop_at_end),
                        .cmd_valid(r_i2c_cmd_valid),
                        .cmd_ready(w_i2c_cmd_ready),
                        .data_in(r_i2c_data_in),
                        .data_in_valid(r_i2c_data_in_valid),
                        .data_in_ready(w_i2c_data_in_ready),
                        .data_in_last(r_i2c_data_in_last),
                        .data_out(w_i2c_data_out),
                        .data_out_valid(w_i2c_data_out_valid),
                        .data_out_ready(r_i2c_data_out_ready),
                        .data_out_last(w_i2c_data_out_last),
                        .scl_i(i_scl),
                        .scl_o(o_scl),
                        .scl_t(t_scl),
                        .sda_i(i_sda),
                        .sda_o(o_sda),
                        .sda_t(t_sda),
                        .busy(o_busy),
                        .bus_control(w_i2c_bus_control),
                        //.bus_active(bus_active),
                        .missed_ack(w_i2c_missed_ack),
                        .prescale(i_prescale));
                        //.stop_on_idle(stop_on_idle));

    assign o_page_b0 = r_page_bytes[0];
    assign o_page_b1 = r_page_bytes[1];
    assign o_page_b2 = r_page_bytes[2];
    assign o_page_b3 = r_page_bytes[3];
    assign o_page_b4 = r_page_bytes[4];
    assign o_page_b5 = r_page_bytes[5];
    assign o_page_b6 = r_page_bytes[6];
    assign o_page_b7 = r_page_bytes[7];

    always @ (posedge clk) begin
        if (reset) begin
            r_state <= `I2C_EEPROM_STATE_IDLE;
            r_nxt_state <= `I2C_EEPROM_STATE_IDLE;
            r_i2c_cmd_write <= 0;
            r_i2c_cmd_write_m <= 0;
            r_i2c_cmd_read_m <= 0;
            r_i2c_cmd_valid <= 0;
            r_i2c_set_stop_at_end <= 0;
            r_i2c_data_in_valid <= 0;
            r_i2c_data_in_last <= 0;
            r_i2c_data_out_ready <= 0;
            r_byte_idx <= 0;
            o_done <= 0;
        end
        else begin
            case (r_state)
                `I2C_EEPROM_STATE_IDLE: begin
                    if (i_start) begin
                        if (w_i2c_cmd_ready) begin
                            if (i_mode) begin
                                // We write multiple bytes followed by the memory address byte.
                                // We indicate the stop condition now. 
                                // After writing all bytes, the stop condition is set.
                                r_i2c_cmd_write <= 0;
                                r_i2c_cmd_write_m <= 1'b1;
                                r_i2c_set_stop_at_end <= 1'b1;
                            end
                            else begin
                                // We write only the memory address byte to set the starting address. 
                                // We don't indicate the stop condition now since we are going to read 
                                // afterwards.  
                                r_i2c_cmd_write <= 1'b1;
                                r_i2c_cmd_write_m <= 0;
                                r_i2c_set_stop_at_end <= 1'b0;
                            end
                            r_i2c_cmd_read_m <= 0;
                            r_i2c_cmd_valid <= 1'b1;
                            r_i2c_data_in_valid <= 0;
                            r_i2c_data_in_last <= 0;
                            r_i2c_data_out_ready <= 0;
                            r_byte_idx <= 0;
                            r_mode <= i_mode;
                            r_i2c_dev_addr <= i_dev_addr;
                            r_i2c_mem_addr <= i_page_addr;
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

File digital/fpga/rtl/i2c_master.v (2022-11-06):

/*

Copyright (c) 2015-2017 Alex Forencich

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
*/

// Language: Verilog 2001

`timescale 1ns / 1ps

/*
 * I2C master
 */
module i2c_master (
    input  wire        clk,
    input  wire        rst,

    /*
     * Host interface
     */
    input  wire [6:0]  cmd_address,
    input  wire        cmd_start,
    input  wire        cmd_read,
    input  wire        cmd_write,
    input  wire        cmd_write_multiple,
    input  wire        cmd_stop,
    input  wire        cmd_valid,
    output wire        cmd_ready,

    input  wire [7:0]  data_in,
    input  wire        data_in_valid,
    output wire        data_in_ready,
    input  wire        data_in_last,

    output wire [7:0]  data_out,
    output wire        data_out_valid,
    input  wire        data_out_ready,
    output wire        data_out_last,

    /*
     * I2C interface
     */
    input  wire        scl_i,
    output wire        scl_o,
    output wire        scl_t,
    input  wire        sda_i,
    output wire        sda_o,
    output wire        sda_t,

    /*
     * Status
     */
    output wire        busy,
    output wire        bus_control,
    output wire        bus_active,
    output wire        missed_ack,

    /*
     * Configuration
     */
    input  wire [15:0] prescale,
    input  wire        stop_on_idle
);

/*
Notes From Kasun:

read
    * cmd_valid should be set high for the entire period of reading except for the last byte.
      cmd_valid should be set low before reading the last byte i.e. before data_out_valid 
      becomes high for the last byte.  
 */

/*

I2C

Read
    __    ___ ___ ___ ___ ___ ___ ___         ___ ___ ___ ___ ___ ___ ___ ___     ___ ___ ___ ___ ___ ___ ___ ___        __
sda   \__/_6_X_5_X_4_X_3_X_2_X_1_X_0_\_R___A_/_7_X_6_X_5_X_4_X_3_X_2_X_1_X_0_\_A_/_7_X_6_X_5_X_4_X_3_X_2_X_1_X_0_\_A____/
    ____   _   _   _   _   _   _   _   _   _   _   _   _   _   _   _   _   _   _   _   _   _   _   _   _   _   _   _   ____
scl  ST \_/ \_/ \_/ \_/ \_/ \_/ \_/ \_/ \_/ \_/ \_/ \_/ \_/ \_/ \_/ \_/ \_/ \_/ \_/ \_/ \_/ \_/ \_/ \_/ \_/ \_/ \_/ \_/ SP

Write
    __    ___ ___ ___ ___ ___ ___ ___ ___     ___ ___ ___ ___ ___ ___ ___ ___     ___ ___ ___ ___ ___ ___ ___ ___ ___    __
sda   \__/_6_X_5_X_4_X_3_X_2_X_1_X_0_/ W \_A_/_7_X_6_X_5_X_4_X_3_X_2_X_1_X_0_\_A_/_7_X_6_X_5_X_4_X_3_X_2_X_1_X_0_/ N \__/
    ____   _   _   _   _   _   _   _   _   _   _   _   _   _   _   _   _   _   _   _   _   _   _   _   _   _   _   _   ____
scl  ST \_/ \_/ \_/ \_/ \_/ \_/ \_/ \_/ \_/ \_/ \_/ \_/ \_/ \_/ \_/ \_/ \_/ \_/ \_/ \_/ \_/ \_/ \_/ \_/ \_/ \_/ \_/ \_/ SP

Commands:

read
    read data byte
    set start to force generation of a start condition
    start is implied when bus is inactive or active with write or different address
    set stop to issue a stop condition after reading current byte
    if stop is set with read command, then data_out_last will be set

write
    write data byte
    set start to force generation of a start condition
    start is implied when bus is inactive or active with read or different address
    set stop to issue a stop condition after writing current byte

write multiple
    write multiple data bytes (until data_in_last)
    set start to force generation of a start condition
    start is implied when bus is inactive or active with read or different address
    set stop to issue a stop condition after writing block

stop
    issue stop condition if bus is active

Status:

busy
    module is communicating over the bus

bus_control
    module has control of bus in active state

bus_active
    bus is active, not necessarily controlled by this module

missed_ack
    strobed when a slave ack is missed

Parameters:

prescale
    set prescale to 1/4 of the minimum clock period in units
    of input clk cycles (prescale = Fclk / (FI2Cclk * 4))

stop_on_idle
    automatically issue stop when command input is not valid

Example of interfacing with tristate pins:
(this will work for any tristate bus)

assign scl_i = scl_pin;
assign scl_pin = scl_t ? 1'bz : scl_o;
assign sda_i = sda_pin;
assign sda_pin = sda_t ? 1'bz : sda_o;

Equivalent code that does not use *_t connections:
(we can get away with this because I2C is open-drain)

assign scl_i = scl_pin;
assign scl_pin = scl_o ? 1'bz : 1'b0;
assign sda_i = sda_pin;
assign sda_pin = sda_o ? 1'bz : 1'b0;

Example of two interconnected I2C devices:

assign scl_1_i = scl_1_o & scl_2_o;
assign scl_2_i = scl_1_o & scl_2_o;
assign sda_1_i = sda_1_o & sda_2_o;
assign sda_2_i = sda_1_o & sda_2_o;

Example of two I2C devices sharing the same pins:

assign scl_1_i = scl_pin;
assign scl_2_i = scl_pin;
assign scl_pin = (scl_1_o & scl_2_o) ? 1'bz : 1'b0;
assign sda_1_i = sda_pin;
assign sda_2_i = sda_pin;
assign sda_pin = (sda_1_o & sda_2_o) ? 1'bz : 1'b0;

Notes:

scl_o should not be connected directly to scl_i, only via AND logic or a tristate
I/O pin.  This would prevent devices from stretching the clock period.

*/

localparam [4:0]
    STATE_IDLE = 4'd0,
    STATE_ACTIVE_WRITE = 4'd1,
    STATE_ACTIVE_READ = 4'd2,
    STATE_START_WAIT = 4'd3,
    STATE_START = 4'd4,
    STATE_ADDRESS_1 = 4'd5,
    STATE_ADDRESS_2 = 4'd6,
    STATE_WRITE_1 = 4'd7,
    STATE_WRITE_2 = 4'd8,
    STATE_WRITE_3 = 4'd9,
    STATE_READ = 4'd10,
    STATE_STOP = 4'd11;

reg [4:0] state_reg = STATE_IDLE, state_next;

localparam [4:0]
    PHY_STATE_IDLE = 5'd0,
    PHY_STATE_ACTIVE = 5'd1,
    PHY_STATE_REPEATED_START_1 = 5'd2,
    PHY_STATE_REPEATED_START_2 = 5'd3,
    PHY_STATE_START_1 = 5'd4,
    PHY_STATE_START_2 = 5'd5,
    PHY_STATE_WRITE_BIT_1 = 5'd6,
    PHY_STATE_WRITE_BIT_2 = 5'd7,
    PHY_STATE_WRITE_BIT_3 = 5'd8,
    PHY_STATE_READ_BIT_1 = 5'd9,
    PHY_STATE_READ_BIT_2 = 5'd10,
    PHY_STATE_READ_BIT_3 = 5'd11,
    PHY_STATE_READ_BIT_4 = 5'd12,
    PHY_STATE_STOP_1 = 5'd13,
    PHY_STATE_STOP_2 = 5'd14,
    PHY_STATE_STOP_3 = 5'd15;

reg [4:0] phy_state_reg = STATE_IDLE, phy_state_next;

reg phy_start_bit;
reg phy_stop_bit;
reg phy_write_bit;
reg phy_read_bit;
reg phy_release_bus;

reg phy_tx_data;

reg phy_rx_data_reg = 1'b0, phy_rx_data_next;

reg [6:0] addr_reg = 7'd0, addr_next;
reg [7:0] data_reg = 8'd0, data_next;
reg last_reg = 1'b0, last_next;

reg mode_read_reg = 1'b0, mode_read_next;
reg mode_write_multiple_reg = 1'b0, mode_write_multiple_next;
reg mode_stop_reg = 1'b0, mode_stop_next;

reg [16:0] delay_reg = 16'd0, delay_next;
reg delay_scl_reg = 1'b0, delay_scl_next;
reg delay_sda_reg = 1'b0, delay_sda_next;

reg [3:0] bit_count_reg = 4'd0, bit_count_next;

reg cmd_ready_reg = 1'b0, cmd_ready_next;

reg data_in_ready_reg = 1'b0, data_in_ready_next;

reg [7:0] data_out_reg = 8'd0, data_out_next;
reg data_out_valid_reg = 1'b0, data_out_valid_next;
reg data_out_last_reg = 1'b0, data_out_last_next;

reg scl_i_reg = 1'b1;
reg sda_i_reg = 1'b1;

reg scl_o_reg = 1'b1, scl_o_next;
reg sda_o_reg = 1'b1, sda_o_next;

reg last_scl_i_reg = 1'b1;
reg last_sda_i_reg = 1'b1;
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

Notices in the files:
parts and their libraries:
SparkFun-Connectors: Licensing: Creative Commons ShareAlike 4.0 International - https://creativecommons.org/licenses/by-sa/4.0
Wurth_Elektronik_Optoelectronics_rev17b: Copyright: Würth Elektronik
